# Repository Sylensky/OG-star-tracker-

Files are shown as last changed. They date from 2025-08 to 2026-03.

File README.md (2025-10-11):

# OG-star-tracker-

Is a fully 3d printed upgradable star tracker that you can make for 60$, I have been working on it for the past two years. It can handle
up to 300mm and 2.5kg. It's also upgradable which means that you can add a another axis which would allow you to use go-to.Don't hesitate to ask me. 
- [List of parts](https://docs.google.com/spreadsheets/d/1kcgIab0JqNLg5WMselIyCQLZJsu3P-vXLvSJgl1yHa8)
- [Assembly video](https://www.youtube.com/watch?v=97YKJrmOWHY)

## Table of Contents
- [Old v1 of the Project](v1/README.md)
- [Mechanics](mechanics/README.md)
- [Firmware](esp32_wireless_control/README.md)
- [Community Upgrades](community_upgrades/README.md)

The kit can be purchased for around 150$ on [ogstartech.com](https://www.ogstartech.com/start/). There is a [discord](https://discord.gg/dyFKm79gKJ) for those who are interested or would want to ask me a few questions. New STLs are
on [printables](https://www.printables.com/model/348574-og-star-tracker).

[DeepWiki](https://deepwiki.com/OG-star-tech/OG-star-tracker-/1-overview) Provides a very detailed documentation of the project.

## License

This work is licensed under a
[Creative Commons Attribution-NonCommercial-ShareAlike 4.0 International License](http://creativecommons.org/licenses/by-nc-sa/4.0/)



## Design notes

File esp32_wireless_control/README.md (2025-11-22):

# OG Star Tracker : Wireless Control Hardware (Rev 2.0)

This simple PCB and firmware intends to make it easier to control the OG Star Tracker. If you have any suggestions/ideas about new features or would like to contribute, post in the OG star tracker [discord server](https://discord.com/invite/dyFKm79gKJ) or message me (Discord: jahh#8924).
If you like this work, feel free to connect with me on [Github](https://github.com/jugal2001) or [Linkedin](https://www.linkedin.com/in/jugaljesing/).
### Features:
- Wirelessly Control the tracker from your phone/laptop by connecting to a webpage
- Supports AP (Access Point) and STA (Station) mode
 -- AP  : The ESP32 will create a wifi network which you can connect to
 -- STA : The ESP32 connects to an existing wifi network specified by you, Ex: phone hotspot. (Not fully tested)
- Integrated intervalometer which can control your camera shutter, no need to buy extra hardware. Exposures can be controlled via the webpage
  - Intervalometer Modes:
    - Long Exposure Still: Classic astro mode with tracking to get long exposures on the same target. Optional dithering.
    - Long Exposure Movie: Long exposures with tracking and dither plus at the end of a set of exposures the axis is rewound (a frame) and the next set started. This give the ability to create a movie          of the night sky moving over a terrestrial object when couple with a video making software.
    -  Day Time Lapse: Standard time lapse with exposure settings controlled by the camera.
    -  Day Time Lapse with Pan: Standard time lapse with exposure settings controlled by the camera plus a pan of X degrees in between every exposure.
- Presets : Up to 10 preset intervalometer settings can be saved for retrieval next session.
- USB port to power a Dew Heater
- Slewing supported at different speeds.

*If you would like to buy an assembled PCB, contact Ondra Gejdos in the discord server (Creator of the OGST). Alternatively, if you live in India contact me to buy the PCB.*

## Table of Contents
- [PCB](pcb/README.md)
- [Compiling](docs/compiling.md)
- [API](firmware/website/API.md)
- [Wifi Config](docs/wifi_config.md)
- [Star Catalogue](firmware/catalogues/README.md)
- [Coding Style](docs/coding-style.md)

## Building guide

One can get the full kit from the the official store at [ogstartech.com](https://ogstartech.com/start) or can build the tracker itself based on the instructions given at [printables](https://www.printables.com/model/348574-og-star-tracker)

## Firmware

The firmware for the PCB is provided in this repository and can be compiled and flashed with the given [instructions](docs/compiling.md).
To control the PCB the tracker will create its own wifi access point with the following default credentials:

```
ssid: OG Star Tracker
password: password123
```

After connection was successful the tracker to actually control it access the **tracker.local** in your browser. The ESP32 provides a webserver for convenient controlling.

If one would like to set it own wifi config, check [Wifi Config](docs/wifi_config.md).

## App

If the webserver is not enough there is a app available to improve the accessibility even further.
Check out https://github.com/OndraGejdos/OG-star-tracker-App for more details.

## Contributing

When contributing to the project please make sure to follow the [coding style](docs/coding-style.md) prior creating a pull request.
With this we can make sure to keep a clean and tidy codespace.

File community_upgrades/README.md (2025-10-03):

# Community Upgrades

You can upload your upgrades and modifications here.

Currently the following upgrades are available:

- [Power bank holder](./power_bank_holder/README.md) — Super simple power bank holder from #The1naruto
- [Surveyor tripod adapter](./surveyor_tripod_adapter/README.md) - Surveyor tripod adapter by #unfi_zero
- [Beefier gearbox multicolor](./beefier_gearbox_multicolor/README.md) - Beefier gearbox and multicolor support for certain elements by #Long
- [Illuminated Polarscope](./illuminated_polarscope/README.md) - Illuminated polarscope by #Long

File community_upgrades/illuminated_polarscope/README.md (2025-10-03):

## Illuminated Polarscope Mount

| Polarscope mount | Tracker mounted |
| --- | --- |
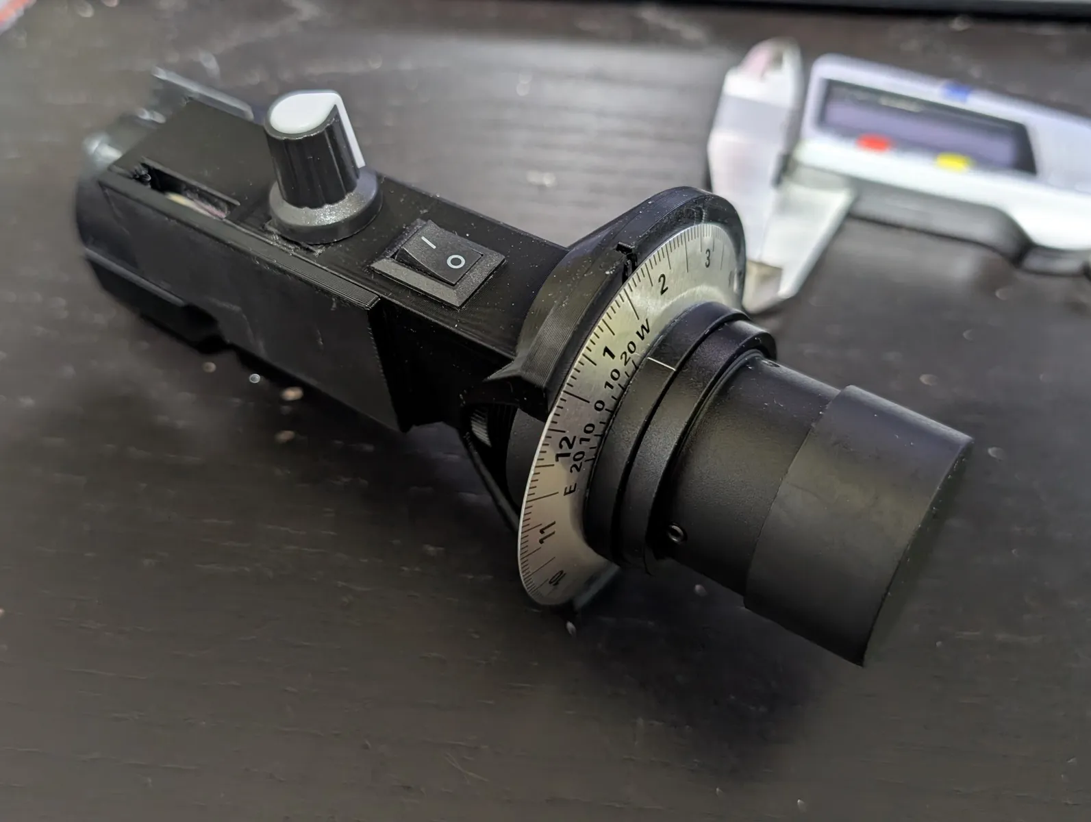
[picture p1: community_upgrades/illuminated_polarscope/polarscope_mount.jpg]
Polarscope mount
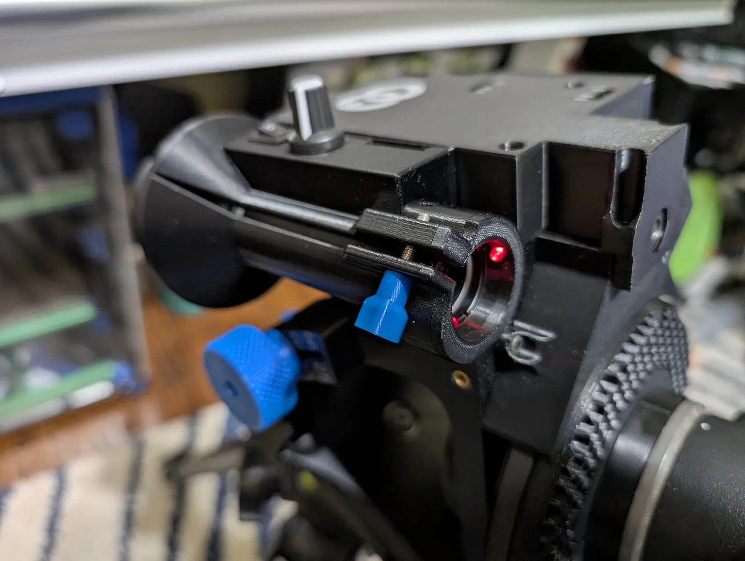
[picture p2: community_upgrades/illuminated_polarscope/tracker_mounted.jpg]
tracker mounted
|  |  |

### Intro:
This is a modified polar mount for the OG Star Tracker V2 that adds some LEDs.  Due to the small space constraints, it isn't the most straightforward build, but it does work pretty well once assembled.  

I used the switch and potentiometer I had on hand, which probably made it harder than just buying a potentiometer with a switch.  I will include the STEP file so it should be pretty easy to modify the electronics compartment to a a switched potentiometer if desired.

**IMPORTANT NOTE**:

This will only work with my single piece gearbox mod [here](../beefier_gearbox_multicolor/README.md) and the upcoming revision of the OG tracker, which will also combine the gearbox 1-2 pieces into a single piece.

### BOM:

- (1) - Polar Scope of this style https://www.amazon.com/dp/B0D2L11C4G 
- (2) - 3mm LEDs
- (2 ft) - >24 gauge wire. the thinner you have, the easier it will be.  I used 26g. 
    - the strands from an ethernet cable will probably work well
- (1 ft) - 20-22g wire.  
    - 20g will work if you have FEP or PTFE wire.
    - Can also use the thin gauge wire and just double/triple up the exposed wire ends.
    - This is used to make the contacts to the 2032 battery.
- (1) - 10 x 15mm mini rocker switch https://www.aliexpress.us/item/3256807801613950.html 
- (1) - WH148 5k ohm potentiometer https://www.aliexpress.us/item/2251832721838471.html 
    - Even lower than 5k is probably better, but all I see is 5k.
    - Any potentiometer that attaches with a nut will probably work as long as it is smaller than the WH148, which is actually kind of big.
- (1) - 2032 battery (3v)
- (1) - 4.2mm brass heatset (from Star Tracker BOM)
- Superglue

Printables link: https://www.printables.com/model/1293141-og-star-tracker-v2-illuminated-polar-scope-mount

The printables link also contains the detailed guide.

Credits go to #Long from discord

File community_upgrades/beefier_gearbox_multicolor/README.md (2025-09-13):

## Surveyor Tripod Adapter

| Front | STL |
| --- | --- |
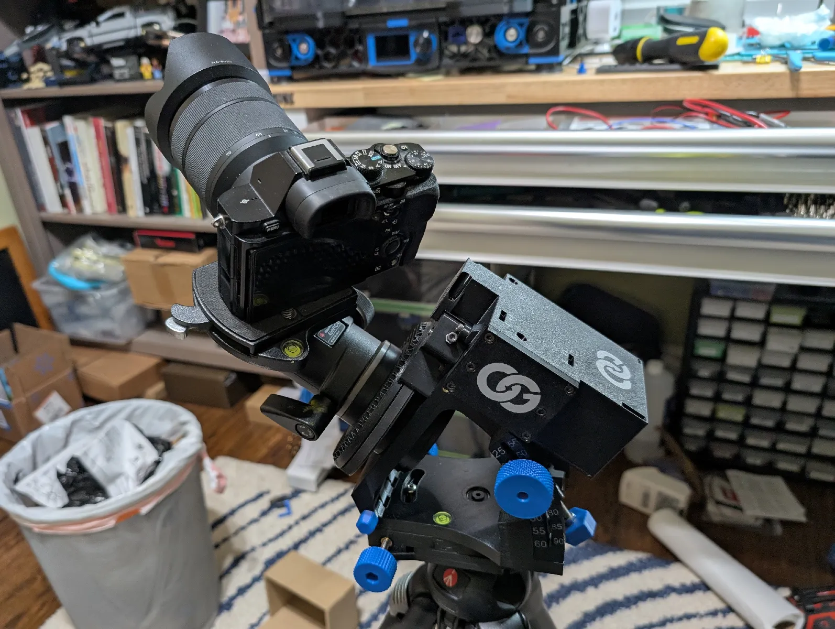
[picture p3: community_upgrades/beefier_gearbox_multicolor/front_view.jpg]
Front view
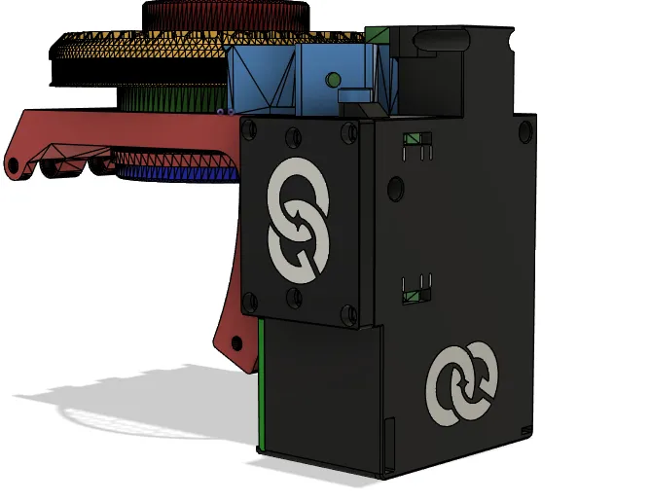
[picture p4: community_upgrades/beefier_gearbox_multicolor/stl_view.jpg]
stl view
|  |  |

### Intro:
These are a few mods to the excellent design of the OG Star Tracker V2.  After building it initially, I wanted to make a few changes to the gearbox to make it a little beefier and make a few small aesthetic changes.  

### Changes impacting strength
- Combines gearbox part 1 and part 2 into one piece for a cleaner look and improved rigidity.
- Thickens the back face of the combined part 1 and 2 for extra rigidity.
- Adds additional bracing to the 625 bearing mount that the tightener pulls against.
- Thickens the mount for the NEMA 17 stepper.  
- Adds additional mounting point for the belt cover to keep it from lifting when pushing against the 400mm belt.

### Other Changes
- The files are now multi-material files with separate bodies for colors so you no longer have to do multi-material painting. 
- Added the logo to the [doors]
- added optional idler carriers
- added camera holder that uses a 3/8"-16 x ½" bolt versus the ¼"-20 x ½"

### Downsides
It is a little more tricky to assemble because access to a couple the bolts is slightly worse.  However, I think it is worth it.

All files are within the **stls** folder. Update will likely land first on the printables page.

Printables link: https://www.printables.com/model/1262022-og-star-tracker-v2-mods-single-piecebeefier-gearbo

Credits go to #Long from discord

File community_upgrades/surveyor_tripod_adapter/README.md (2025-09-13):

## Surveyor Tripod Adapter

| Top | Side |
| --- | --- |
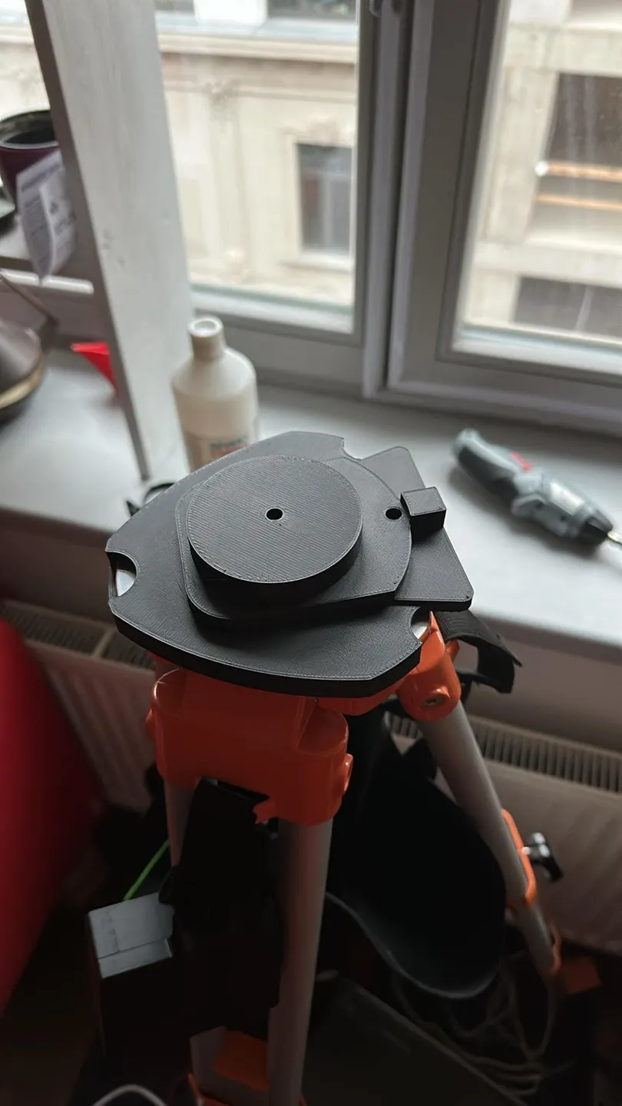
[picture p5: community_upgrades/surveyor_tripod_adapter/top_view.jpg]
Top view
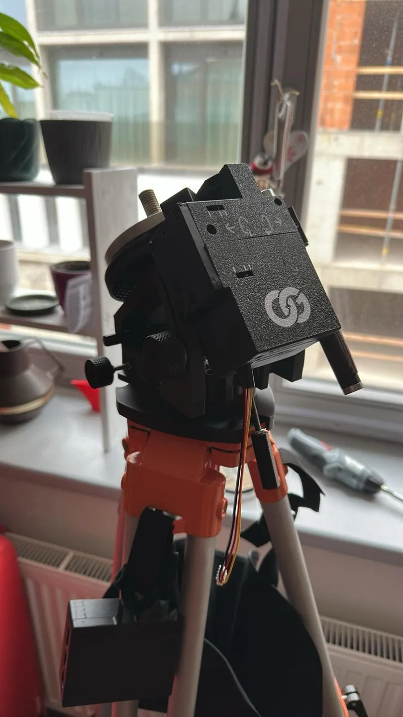
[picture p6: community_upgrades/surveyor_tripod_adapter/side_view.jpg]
Side view
|  |  |

Surveyor tripod adapter so that the OG Star Tracker V2 will not move on the tripod.

perfect fit for https://geo-fennel.de/produkte/stative-und-nivellierlatten/alustative/fs-20

You can test your fit by printing the “size-test.stl” first.

Printables link: https://www.printables.com/model/1151274-og-star-tracker-v2-surveyor-tripod-adapter

Credits go to #unfi_zero from discord

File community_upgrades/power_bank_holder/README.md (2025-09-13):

## Super simple power bank holder

| Front | Back |
| --- | --- |
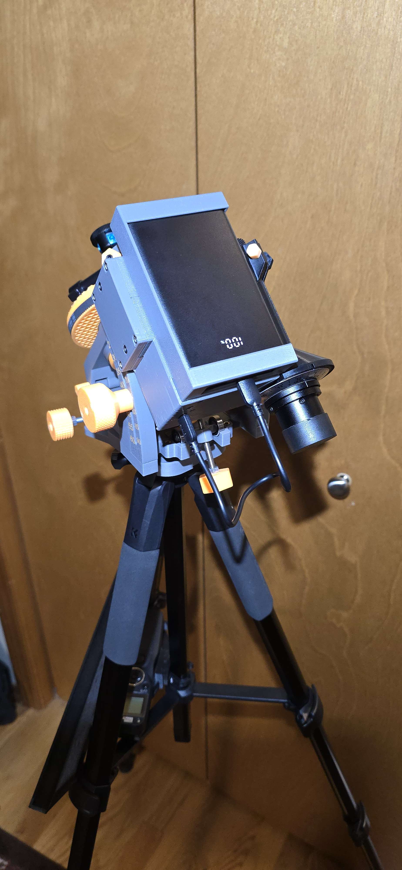
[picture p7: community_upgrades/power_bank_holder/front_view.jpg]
Front view
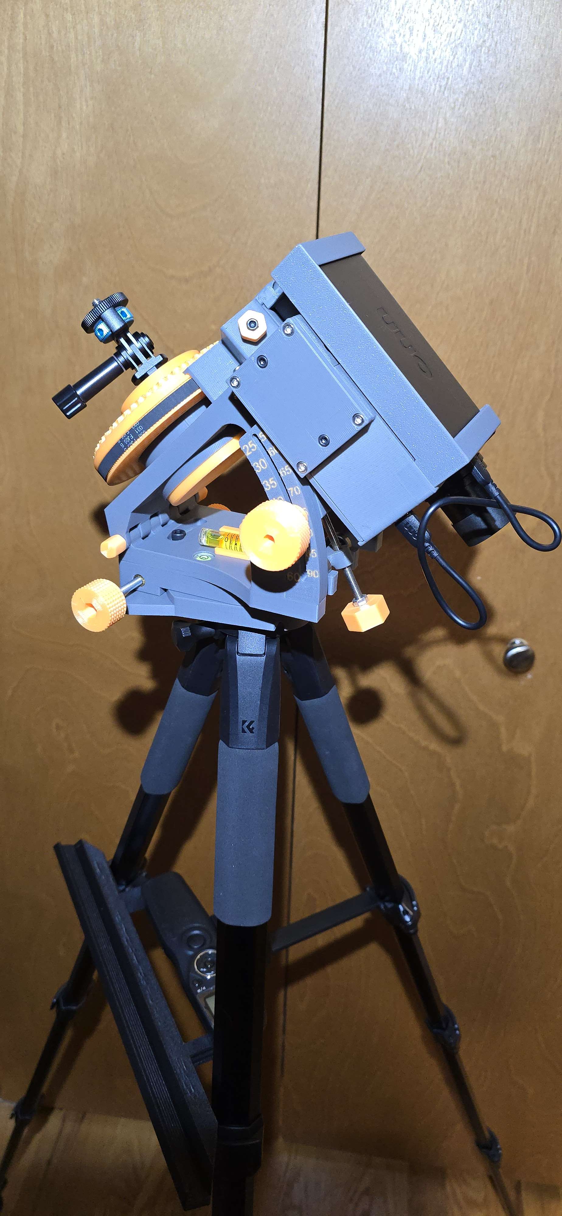
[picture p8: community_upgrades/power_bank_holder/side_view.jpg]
Side view
|  |  |

Super simple design for using the phone mount spot for an ONN 5800mAh power bank to power the tracker

Credits go to #The1naruto from discord

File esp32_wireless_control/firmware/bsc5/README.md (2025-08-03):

# BSC5 Data and Conversion

## Source
- The Yale Bright Star Catalog (BSC5) is available at following link:
  - http://tdc-www.harvard.edu/catalogs/bsc5.html
- Download the main data file (e.g., `bsc5.dat`) from the FTP archive.

## JSON Format Support
The BSC5 class now supports JSON format data for easier integration with modern applications:

### Conversion Scripts
- Python scripts are provided in this folder to convert the BSC5 data to JSON:
  ```sh
  python bsc5_to_json.py
  python bsc5ra_to_json.py
  ```

### Using JSON Data
1. Add the JSON file to your PlatformIO configuration:
   ```ini
   [env:esp32]
   board_build.embed_txtfiles = bsc5/bsc5ra_stars_with_notes.json
   ```

2. Initialize the BSC5 class with JSON data:
   ```cpp
   #include "bsc5ra.h"
   
   // Load JSON data
   bsc5.loadFromJson(bsc5ra_stars_with_notes_json_start);
   
   // Find star by catalog number
   StarEntry star;
   if (bsc5.findStarByXno(15, star)) {
       star.print();
   }
   
   // Find star by name (partial, case-insensitive)
   if (bsc5.findStarByName("deneb", star)) {
       star.print();
   }
   ```

### Available Methods
- `findStarByXno(float xno, StarEntry& result)` - Find star by catalog number
- `findStarByName(const String& name_fragment, StarEntry& result)` - Find star by name (supports partial matching)
- `printStar(const StarEntry& star)` - Print star information
- `getStarCount()` - Get total number of stars loaded

## Notes
- The JSON format includes star names, notes, and proper motion data
- Name search is case-insensitive and supports partial matching (e.g., "deneb" will find "DENEB")
- Original binary format is still supported for backward compatibility

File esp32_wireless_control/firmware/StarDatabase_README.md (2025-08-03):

# StarDatabase - Unified Catalog System

The StarDatabase system provides a unified interface for accessing both stellar and deep-sky object catalogs in the ESP32 star tracker firmware.

## Overview

The StarDatabase acts as a parent class that manages multiple astronomical catalogs:
- **BSC5 (Yale Bright Star Catalog)**: Contains ~9,000 bright stars with proper names
- **NGC 2000.0**: Contains nebulae, galaxies, star clusters, and other deep-sky objects

## Architecture

```
StarDatabase (Parent Class)
├── BSC5 Integration (Stars)
│   ├── Star search by name/fragment
│   ├── Stellar coordinates and magnitudes
│   └── Spectral types and proper motion
└── NGC2000 Integration (Deep-Sky Objects)
    ├── Object search by name/type/constellation
    ├── Deep-sky coordinates and magnitudes
    └── Object sizes and descriptions
```

## Key Features

### 1. Unified Search Interface
```cpp
UnifiedEntry obj;

// Search across all loaded databases
starDB.findByName("Sirius", obj);
starDB.findByNameFragment("NGC", obj);
starDB.findBrighterThan(3.0, obj);
```

### 2. Database Switching
```cpp
// Use only stars
starDB.setActiveDatabase(DB_BSC5);

// Use only deep-sky objects  
starDB.setActiveDatabase(DB_NGC2000);

// Search both databases
starDB.setActiveDatabase(DB_BOTH);
```

### 3. Type-Specific Searches
```cpp
// Find stellar objects only
starDB.findStar("Deneb", obj);

// Find deep-sky objects only
starDB.findDeepSkyObject("NGC1234", obj);
```

### 4. Coordinate Utilities
```cpp
// Format coordinates for display
String coords = starDB.formatCoordinates(ra_deg, dec_deg);

// Calculate angular separation
double separation = starDB.angularSeparation(ra1, dec1, ra2, dec2);
```

## Data Structures

### UnifiedEntry
Common structure for all astronomical objects:
```cpp
struct UnifiedEntry {
    String name;           // Object name
    String type_str;       // Object type
    double ra_deg;         // Right Ascension (degrees)
    double dec_deg;        // Declination (degrees)
    float magnitude;       // Visual magnitude
    String constellation;  // Constellation (if available)
    DatabaseType source_db; // Source database
    bool is_star;          // Stellar object flag
    bool is_deep_sky;      // Deep-sky object flag
    
    // Extended data
    String spectral_type;  // For stars (BSC5)
    float size_arcmin;     // For deep-sky objects (NGC)
    String notes;          // Additional information
};
```

## Usage Examples

### Basic Setup
```cpp
#include "star_database.h"

void setup() {
    // Load catalogs
    starDB.loadBSC5(bsc5_json_data);
    starDB.loadNGC2000(ngc_json_data);
    
    // Set active database
    starDB.setActiveDatabase(DB_BOTH);
    
    // Print database info
    starDB.printDatabaseInfo();
}
```

### Object Search
```cpp
UnifiedEntry obj;

// Find by exact name
if (starDB.findByName("Vega", obj)) {
    starDB.printObject(obj);
}

// Find by name fragment
if (starDB.findByNameFragment("Alpha", obj)) {
    print_out("Found: %s", obj.name.c_str());
}

// Find bright objects
if (starDB.findBrighterThan(2.0, obj)) {
    print_out("Bright object: %s (mag %.2f)", 
              obj.name.c_str(), obj.magnitude);
}
```

### Telescope Integration
```cpp
// Goto command example
UnifiedEntry target;
if (starDB.findByName("M42", target)) {
    telescope.slewTo(target.ra_deg, target.dec_deg);
    print_out("Slewing to %s at %s", 
              target.name.c_str(),
              target.getCoordinateString().c_str());
}
```

## Database Backends

### BSC5 Integration
- **Data Source**: Yale Bright Star Catalog (5th Edition)
- **Object Count**: ~9,000 stars
- **Coordinate System**: J2000
- **Key Fields**: Name, spectral type, magnitude, proper motion
- **Search Methods**: By name fragment, stellar ID

### NGC2000 Integration  
- **Data Source**: New General Catalogue and Index Catalogue
- **Object Count**: Variable (filtered by magnitude/type)
- **Coordinate System**: J2000
- **Key Fields**: Name, object type, size, constellation
- **Search Methods**: By name, type, constellation, magnitude

## Performance Considerations

### Memory Usage
- Uses ArduinoJson for efficient JSON parsing
- Unified data structures minimize memory overhead
- Lazy loading of catalog data

### Search Performance
- Direct JSON traversal for name-based searches
- Type-specific searches route to appropriate backend
- Caching of frequently accessed objects (future enhancement)

## File Structure

```
firmware/
├── star_database.h              # Main header
├── star_database.cpp            # Implementation
├── star_database_example.cpp    # Usage examples
├── bsc5/
│   ├── bsc5ra.h                # BSC5 star catalog
│   ├── bsc5ra.cpp              # BSC5 implementation
│   └── bsc5ra_stars_with_notes.json
└── ngc/
    ├── ngc2000.h               # NGC catalog
    ├── ngc2000.cpp             # NGC implementation
    └── ngc2000.json
```

## Integration with Existing Code

### UART Output
All output uses the project's `print_out()` function from `uart.h`:
```cpp
print_out("Found object: %s", obj.name.c_str());
```

### JSON Data Loading
Compatible with PlatformIO embedded file system:
```cpp
extern const char bsc5_json_data[];
extern const char ngc_json_data[];
```

### Arduino Framework
Full compatibility with ESP32 Arduino framework and existing project structure.

## Future Enhancements

### Planned Features
1. **Proximity Search**: Find objects near telescope position
2. **Visibility Calculations**: Filter by altitude/azimuth
3. **Observing Lists**: Create custom target lists
4. **Messier Integration**: Cross-reference NGC objects with Messier numbers
5. **Search Caching**: Improve performance for repeated searches

### API Extensions
1. **Multiple Result Search**: Return arrays of matching objects
2. **Advanced Filtering**: By magnitude range, object size, etc.
3. **Coordinate Transformations**: Alt/Az calculations
4. **Time-based Visibility**: Rise/set times and optimal viewing

## Error Handling

The system includes comprehensive error handling:
- JSON parsing validation
- Database loading verification
- Search result validation
- Memory management for large catalogs

## Debugging

Enable detailed output for troubleshooting:
```cpp
starDB.printDatabaseInfo();  // Database status
obj.print();                 // Object details
```

Use the project's existing UART debugging system for consistent logging across all modules.

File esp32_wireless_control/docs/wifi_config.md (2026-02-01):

# Wifi Config

## `platformio.ini` changes

The `platformio.ini` file *must* define a macro `HAVE_WIFI_CONFIG` in order to config to detect wifi configuration:

Example:
```yaml
build_flags =
    -D HAVE_WIFI_CONFIG=1
    -D AP_MODE=1
    -D BINARY_NAME=${ogstartracker.custom_binary_name}
    -D VERSION=${ogstartracker.custom_version}
    -D DEBUG=0
    -D MDNS_NAME='"tracker"'
    -D BUILD_VERSION=\"${ogstartracker.custom_version}\"
    -D INTERNAL_VERSION=7
    -D WIFI_SSID='"OG Star Tracker"'
    -D WIFI_PASSWORD='"password123"'
    -D STEPPER_TYPE=STEPPER_0_9
    -D WEBSERVER_PORT=80
    -D AP_MODE=1
    -D TRACKING_RATE=TRACKING_SIDEREAL
    -Wall -Wextra -Os
```

## `wifi_config.h` file

One must a file called `wifi_config.h` with his/hers own wifi network credentials:

```c
#ifndef _WIFI_CONFIG_H_
#define _WIFI_CONFIG_H_

#define WIFI_SSID "your ssid here"
#define WIFI_PASSWORD "your wifi password"

#endif /* _WIFI_CONFIG_H_ */

```

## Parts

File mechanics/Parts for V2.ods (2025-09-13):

parts | quantity | remarks
M3x40 socket bolt | 4
M3x6 socket bolt | 2
M3x20 socket bolt | 8
M5x25 socket bolt | 1
M5x50 Hex head | 2
M5 ptfe washer | 1
M3x8 socket bolt | 40
M3x16 socket bolt | 4
M5x20 Low profile socket bolt | 1
¼-20x1/2” UNC Hex head | 2
m3 threaded insert | 60
m5 threaded insert | 5
- | 1
M3 nut | 3
M5 nut | 3
M5 self-tightening nuts | 2
¼-20 UNC to 3/8-20 UNC adapter | 2
AXK 5070 needle bearing | 2
AS 5070 Axial bearing washer | 4
KU 5025 plain bearing | 1 | It’s a ptfe lined plain bearing with dimensions of : Inner diameter : 50mm Outer diameter 55mm, Witdth : 25mm
GT2 16 teeth pulley | 3
GT2 48 teeth pulley | 2
GT2 20 teeth idler | 1
GT2 120mm belt | 2
GT2 400mm belt | 1
5x50mm shaft | 2
M5x95mm rod | 1
M5x135mm rod | 1
625 bearing | 10
Round bubble level 12x7mm | 1
Laser or polar scope | 1
4mm hex key | 1
2.5mm hex key | 1
grease, ptfe based | 1
glue | 1
2mm hex key | 1
Round magnet 10x3mm | 4
Round magnet 5x5mm | 2
PCB ( buy at ogstartech.com) | 1 | https://ogstartech.com/product/og-star-tracker-pcb-board/
Stepper motor | 1
cable for stepper motor | 1

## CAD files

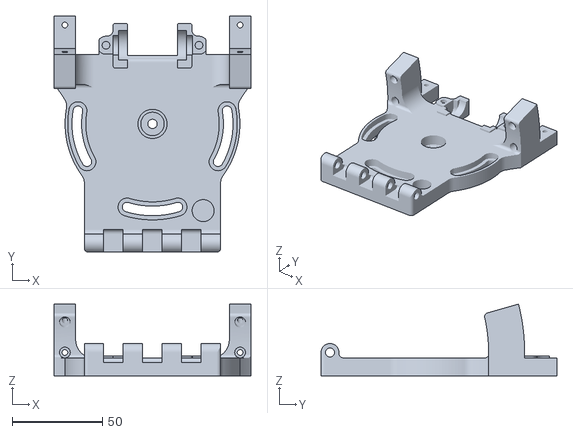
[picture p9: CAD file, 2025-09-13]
mechanics/Heavy duty/main-bottom-part-hd.stl
109.2 x 130.9 x 39.9

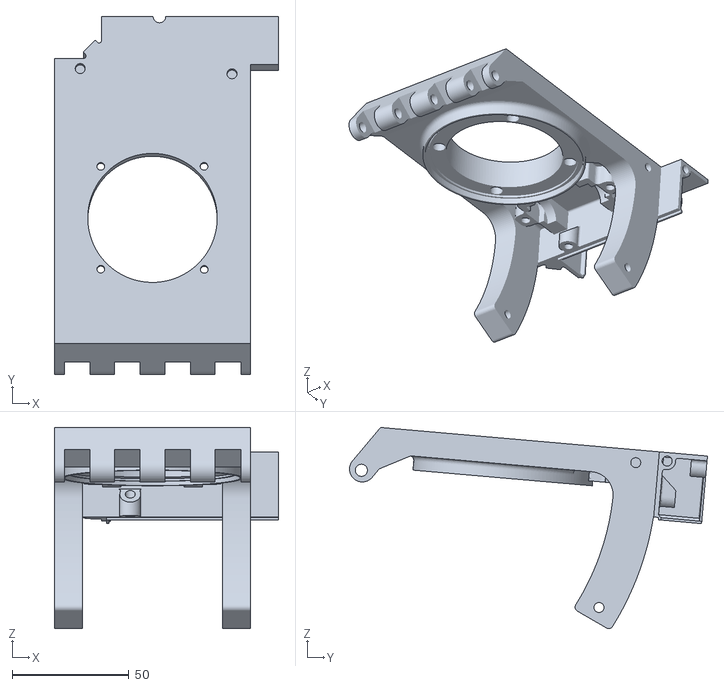
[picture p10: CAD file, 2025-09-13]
mechanics/Heavy duty/main-top-part-hd.stl
96.2 x 153.4 x 86.2

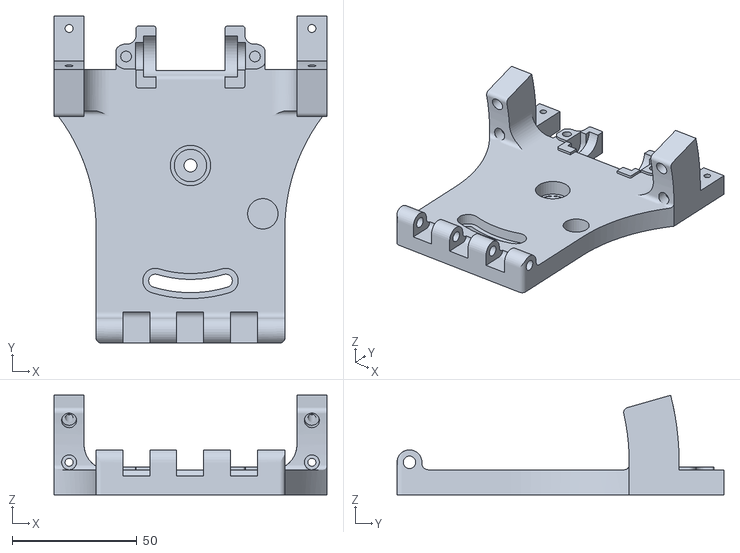
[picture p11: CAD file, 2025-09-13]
mechanics/V2 files/main-bottom-part.stl
109.2 x 130.9 x 39.9

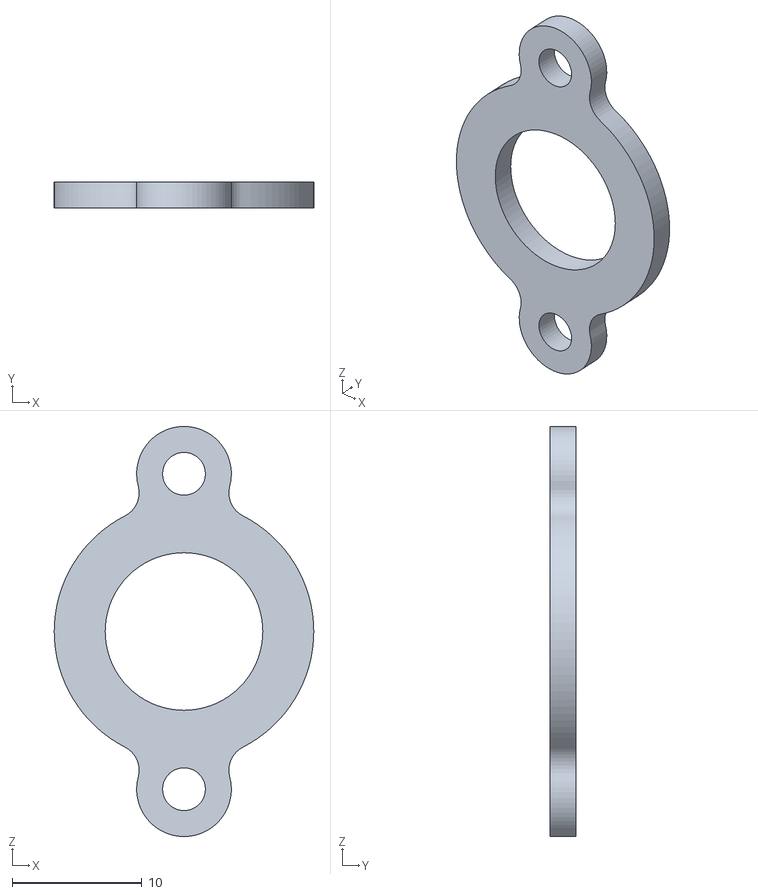
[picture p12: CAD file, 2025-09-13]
mechanics/V2 files/main-gearbox-bearing-holderstl.stl
20.0 x 2.00 x 31.6

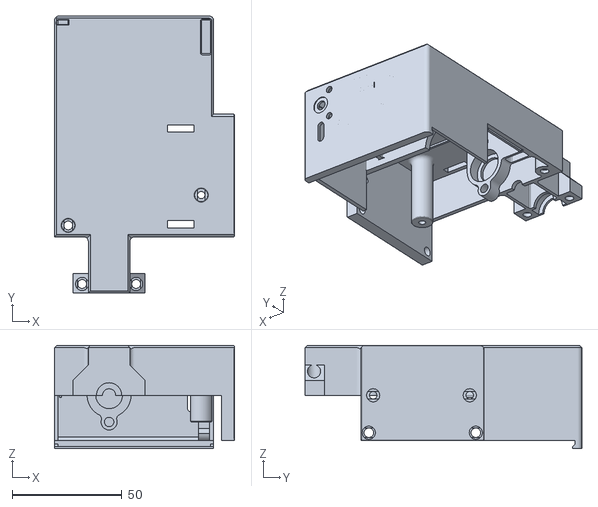
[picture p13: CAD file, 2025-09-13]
mechanics/V2 files/main-gearbox.stl
82.0 x 126.2 x 47.0

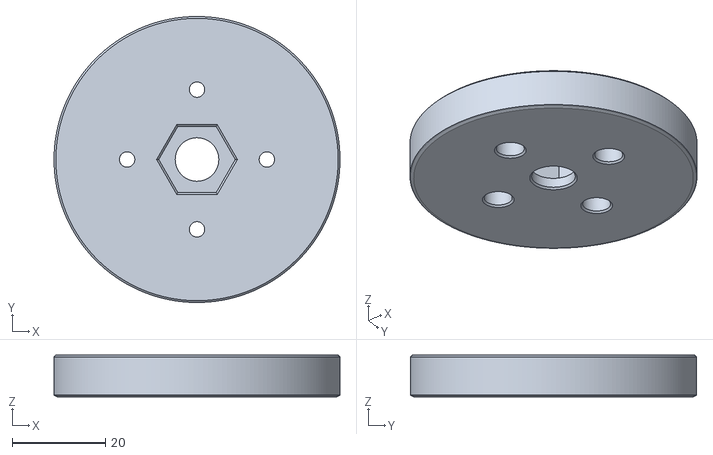
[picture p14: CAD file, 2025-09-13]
community_upgrades/beefier_gearbox_multicolor/stls/camera-holder-3-8-16-x-1-2.stl
61.4 x 61.4 x 9.00

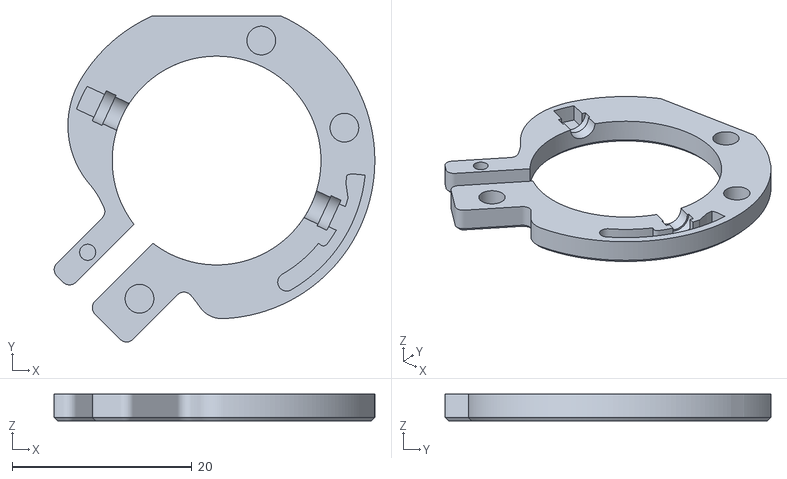
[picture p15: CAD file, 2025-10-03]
community_upgrades/illuminated_polarscope/stls/led-top-cap.stl
35.7 x 36.3 x 3.00

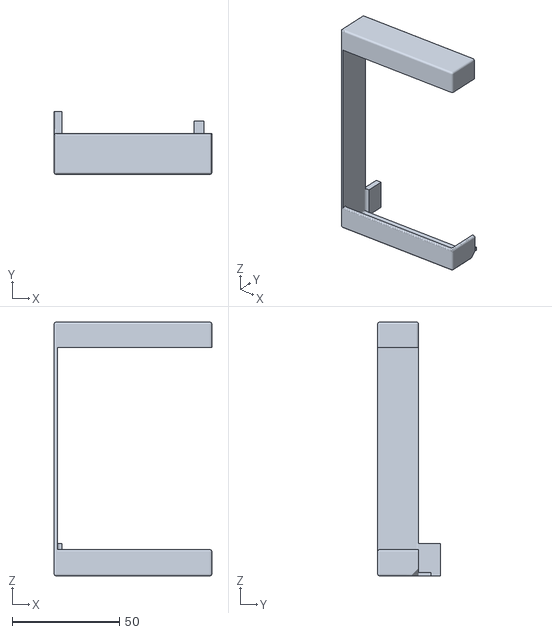
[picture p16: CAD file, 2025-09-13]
community_upgrades/power_bank_holder/OGstartracker ONN battery mount.stl
73.4 x 29.2 x 118.2

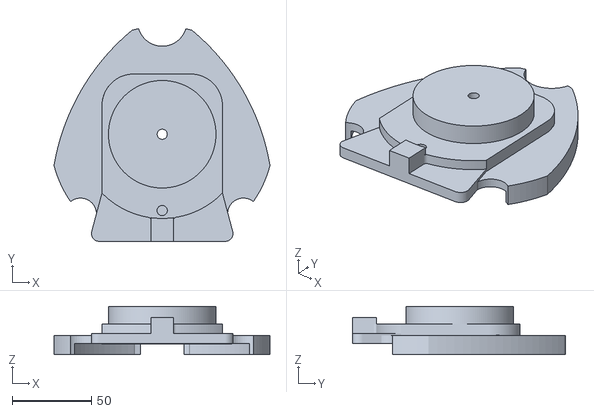
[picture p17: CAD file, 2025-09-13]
community_upgrades/surveyor_tripod_adapter/stationary_part_with_surveyor_adapter2.stl
136.6 x 134.6 x 30.6

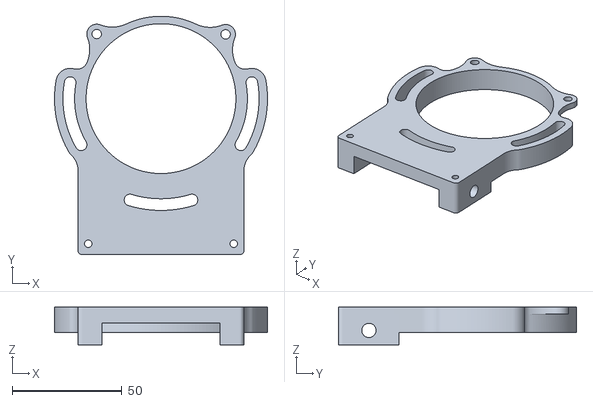
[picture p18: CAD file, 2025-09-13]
mechanics/Heavy duty/middle-part-hd.stl
97.0 x 108.6 x 17.1

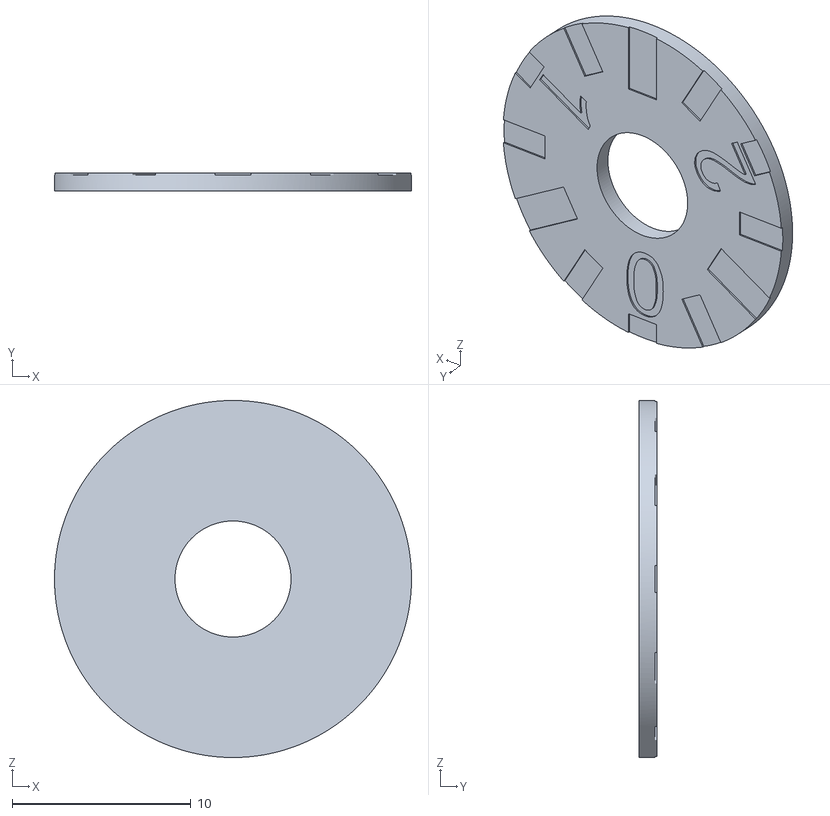
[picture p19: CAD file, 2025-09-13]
mechanics/Manual go-to beta testing/small-scale-2.stl
20.0 x 1.00 x 20.0

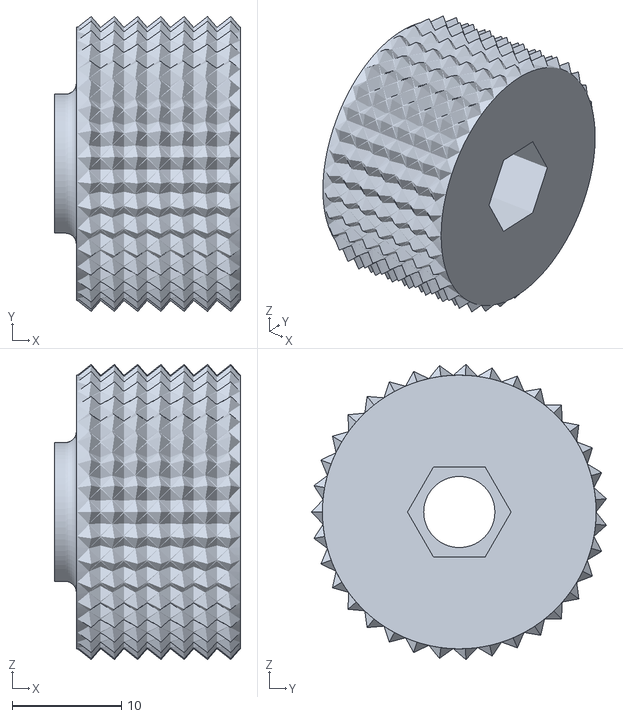
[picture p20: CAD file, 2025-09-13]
mechanics/V2 files/m5-knob.stl
17.0 x 26.9 x 27.0

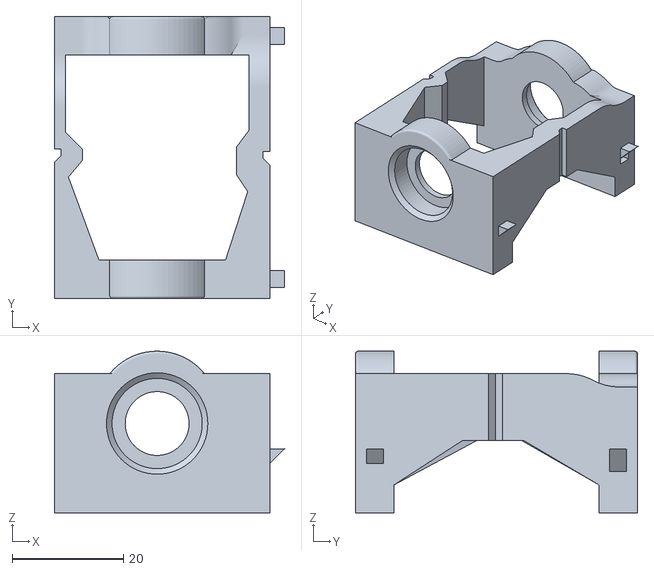
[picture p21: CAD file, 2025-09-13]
community_upgrades/beefier_gearbox_multicolor/stls/tightener-modded-needs_supports.stl
41.3 x 50.7 x 29.1

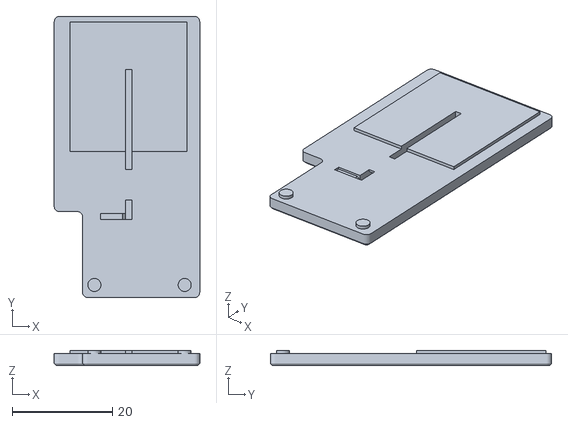
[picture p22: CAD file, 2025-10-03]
community_upgrades/illuminated_polarscope/stls/side-cap.stl
29.0 x 56.0 x 3.00

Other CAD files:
mechanics/V2 files/main-top-part.stl
community_upgrades/surveyor_tripod_adapter/size-test.stl
mechanics/Heavy duty/arcs-for-hd.stl
mechanics/Manual go-to beta testing/vixen-knob.stl
community_upgrades/beefier_gearbox_multicolor/stls/belt-cover-modded-needs_supports.stl
community_upgrades/beefier_gearbox_multicolor/stls/belt-tightener-625-bearing-m5x16mm.stl
community_upgrades/beefier_gearbox_multicolor/stls/belt-tightener-f695-bearing-m5x16mm.stl
community_upgrades/beefier_gearbox_multicolor/stls/doors-modded-with-logo.stl
community_upgrades/beefier_gearbox_multicolor/stls/gearbox-part-1-2-combined-embossed_letters-v11.stl
community_upgrades/beefier_gearbox_multicolor/stls/gearbox-part-1-2-combined-with-multicolor-letters-v11.stl
community_upgrades/beefier_gearbox_multicolor/stls/gearbox-part-3-modded.stl
community_upgrades/illuminated_polarscope/stls/knob.stl
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

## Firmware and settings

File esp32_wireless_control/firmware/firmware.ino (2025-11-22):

#include <ArduinoJson.h>
#include <ESPmDNS.h>
#include <ErriezSerialTerminal.h>
#include <WebServer.h>
#include <WiFi.h>
#include <esp_wifi.h>
#include <freertos/FreeRTOS.h>
#include <string.h>

#include "axis.h"
#include "catalogues/star_database.h"
#include "commands.h"
#include "common_strings.h"
#include "configs/config.h"
#include "eeprom_manager.h"
#include "functions/intervalometer/intervalometer.h"
#include "functions/ota/ota_handler.h"
#include "hardwaretimer.h"
#include "tracking_rates.h"
#include "uart.h"
#include "website/api_handler.h"
#include "website/web_languages.h"
#include "website/website_strings.h"

SerialTerminal term(CLI_NEWLINE_CHAR, CLI_DELIMITER_CHAR);
WebServer server(WEBSERVER_PORT);
Languages language = EN;
StarDatabase* starDatabase = nullptr;
Intervalometer* intervalometer = nullptr;

void uartTask(void* pvParameters);
void consoleTask(void* pvParameters);
void webserverTask(void* pvParameters);
void intervalometerTask(void* pvParameters);
void systemShutdown();

extern const uint8_t _interface_index_html_start[] asm("_binary_interface_index_html_start");
extern const uint8_t _interface_index_html_end[] asm("_binary_interface_index_html_end");

extern const uint8_t _catalogues_ngc_converted_ngc2000_bin_start[] asm(
    "_binary_catalogues_ngc_converted_ngc2000_bin_start");
extern const uint8_t _catalogues_ngc_converted_ngc2000_bin_end[] asm(
    "_binary_catalogues_ngc_converted_ngc2000_bin_end");

extern const uint8_t _catalogues_ngc_converted_ngc2000_compact_bin_start[] asm(
    "_binary_catalogues_ngc_converted_ngc2000_compact_bin_start");
extern const uint8_t _catalogues_ngc_converted_ngc2000_compact_bin_end[] asm(
    "_binary_catalogues_ngc_converted_ngc2000_compact_bin_end");

extern const uint8_t _catalogues_bsc5_converted_bsc5ra_bin_start[] asm(
    "_binary_catalogues_bsc5_converted_bsc5ra_bin_start");
extern const uint8_t _catalogues_bsc5_converted_bsc5ra_bin_end[] asm(
    "_binary_catalogues_bsc5_converted_bsc5ra_bin_end");

extern const uint8_t _catalogues_bsc5_converted_bsc5ra_compact_bin_start[] asm(
    "_binary_catalogues_bsc5_converted_bsc5ra_compact_bin_start");
extern const uint8_t _catalogues_bsc5_converted_bsc5ra_compact_bin_end[] asm(
    "_binary_catalogues_bsc5_converted_bsc5ra_compact_bin_end");

StarDatabase* handleStarDatabase(StarDatabaseType type)
{
    StarDatabase* db = nullptr;
    const uint8_t* bin_start = nullptr;
    const uint8_t* bin_end = nullptr;
    size_t len = 0;

    if (starDatabase != nullptr && starDatabase->getDatabaseType() == type)
        return starDatabase; // Return existing instance if already loaded

    if (starDatabase != nullptr)
    {
        starDatabase->unloadDatabase();
        delete starDatabase;
        starDatabase = nullptr;
    }

    switch (type)
    {
        case DB_NGC2000:
            bin_start = _catalogues_ngc_converted_ngc2000_bin_start;
            bin_end = _catalogues_ngc_converted_ngc2000_bin_end;
            len = bin_end - bin_start;
            break;
        case DB_NGC2000_COMPACT:
            bin_start = _catalogues_ngc_converted_ngc2000_compact_bin_start;
            bin_end = _catalogues_ngc_converted_ngc2000_compact_bin_end;
            len = bin_end - bin_start;
            break;
        case DB_BSC5:
            bin_start = _catalogues_bsc5_converted_bsc5ra_bin_start;
            bin_end = _catalogues_bsc5_converted_bsc5ra_bin_end;
            len = bin_end - bin_start;
            break;
        case DB_BSC5_COMPACT:
            bin_start = _catalogues_bsc5_converted_bsc5ra_compact_bin_start;
            bin_end = _catalogues_bsc5_converted_bsc5ra_compact_bin_end;
            len = bin_end - bin_start;
            break;
        default:
            print_out("Error: Unsupported database type %d", type);
            return nullptr;
    }

    db = new StarDatabase(type, bin_start, bin_end);
    if (!db->loadDatabase((const char*) bin_start, len))
    {
        delete db;
        return nullptr;
    }

    return db;
}

String getChipID()
{
    uint64_t chipid = ESP.getEfuseMac();
    uint8_t baseMac[6];

    // Extract each byte of the MAC address from the chipid
    baseMac[0] = (chipid >> 40) & 0xFF;
    baseMac[1] = (chipid >> 32) & 0xFF;
    baseMac[2] = (chipid >> 24) & 0xFF;
    baseMac[3] = (chipid >> 16) & 0xFF;
    baseMac[4] = (chipid >> 8) & 0xFF;
    baseMac[5] = chipid & 0xFF;

    // Create a String object to hold the formatted ID
    String id = String(baseMac[4], HEX) + String(baseMac[5], HEX);
    return id;
}

#if DEBUG == 1
void handleNotFound()
{
    print_out("HTTP 404: %s %s", server.method() == HTTP_GET ? "GET" : "POST",
              server.uri().c_str());
    print_out("  Client: %s", server.client().remoteIP().toString().c_str());
    print_out("  User-Agent: %s", server.header("User-Agent").c_str());
    server.send(404, MIME_TYPE_TEXT, "Not Found");
}
#endif

void setupWireless()
{
#if AP_MODE == 1
    // Create unique SSID for each device
    String chipID = getChipID();
    char ssid[32];
    sprintf(ssid, "%s#%s", WIFI_SSID, chipID.c_str());

    WiFi.mode(WIFI_MODE_AP);
    print_out("Creating Wifi Network: %s", ssid);

    // Configure AP with specific IP settings
    IPAddress local_IP(192, 168, 4, 1);
    IPAddress gateway(192, 168, 4, 1);
    IPAddress subnet(255, 255, 255, 0);

    if (!WiFi.softAPConfig(local_IP, gateway, subnet))
    {
        print_out("Failed to configure AP IP settings");
    }

    if (!WiFi.softAP(ssid, WIFI_PASSWORD))
    {
        print_out("Failed to start AP");
    }

    vTaskDelay(1000); // Give more time for AP to initialize

    // ANDROID 10 WORKAROUND==================================================
    // set new WiFi configurations
    print_out("Applying Android 10 compatibility workaround...");
    WiFi.disconnect();
    /*Stop wifi to change config parameters*/
    esp_wifi_stop();
    esp_wifi_deinit();
    /*Disabling AMPDU RX is necessary for Android 10 support*/
    wifi_init_config_t my_config = WIFI_INIT_CONFIG_DEFAULT(); // We use the default config ...
    my_config.ampdu_rx_enable = 0;                             //... and modify only what we want.
    print_out("WiFi: Disabled AMPDU...");
    esp_wifi_init(&my_config); // set the new config = "Disable AMPDU"
    esp_wifi_start();          // Restart WiFi

    // Restart AP after workaround
    WiFi.mode(WIFI_MODE_AP);
    if (!WiFi.softAPConfig(local_IP, gateway, subnet))
    {
        print_out("Failed to reconfigure AP IP settings after workaround");
    }
    if (!WiFi.softAP(ssid, WIFI_PASSWORD))
    {
        print_out("Failed to restart AP after workaround");
    }

    vTaskDelay(1000);
    // ANDROID 10 WORKAROUND==================================================

    print_out("AP setup complete. Checking status...");
    print_out("AP Status: %s", WiFi.softAPgetStationNum() >= 0 ? "Active" : "Inactive");
    print_out("WiFi Mode: %d", WiFi.getMode());
#else
    WiFi.mode(WIFI_MODE_STA); // Set ESP32 in station mode
    WiFi.begin(WIFI_SSID, WIFI_PASSWORD);
    print_out("Connecting to SSID: %s with password: %s", WIFI_SSID, WIFI_PASSWORD);
    print_out("Connecting to Network in STA mode");
    while (WiFi.status() != WL_CONNECTED)
    {
        vTaskDelay(1000);
        print_out(".");
    }
#endif

    // Initialize OTA Handler (singleton)
    OTAHandler::getInstance().init(&server);

    // Register all REST API endpoints using ApiHandler
    ApiHandler::getInstance().init(&server);
    ApiHandler::getInstance().registerEndpoints();

#if DEBUG == 1
    server.onNotFound(handleNotFound);
    print_out("Web server debug logging enabled");
#endif

    // Start the server
    server.begin();

#if AP_MODE == 1
    IPAddress apIP = WiFi.softAPIP();
    print_out("AP IP address: %s", apIP.toString().c_str());
    if (apIP == IPAddress(0, 0, 0, 0))
    {
        print_out("ERROR: AP IP is 0.0.0.0 - AP may not be configured correctly");
        print_out("WiFi Mode: %d", WiFi.getMode());
        print_out("AP Status: %d", WiFi.status());
    }
#else
    print_out("STA IP address: %s", WiFi.localIP().toString().c_str());
#endif

    print_out("Starting mDNS responder");
    if (!MDNS.begin(MDNS_NAME))
    {
        print_out("Error starting mDNS responder");
        return;
    }
    print_out("mDNS responder started");

    MDNS.addService("http", "tcp", WEBSERVER_PORT);
    MDNS.addServiceTxt("http", "tcp", "ogtracker", "1");
    MDNS.addServiceTxt("http", "tcp", "version", BUILD_VERSION);

    MDNS.addService("ogtracker", "tcp", WEBSERVER_PORT);
    MDNS.addServiceTxt("ogtracker", "tcp", "version", BUILD_VERSION);
}

void setup()
{
    // Start the debug serial connection
    setup_uart(&Serial, 115200);

    // start UART task before any usage of print_out
    if (xTaskCreatePinnedToCore(uartTask, "uart", 4096, NULL, 1, NULL, 1))
    {
        print_out_tbl(TSK_CLEAR_SCREEN);
        print_out_tbl(TSK_START_UART);
    }

    print_out_tbl(HEAD_LINE);
    print_out_tbl(HEAD_LINE_TRACKER);
    print_out("***         Running on %d MHz         ***", getCpuFrequencyMhz());
    print_out("***     Dual Core Setup: ISR Core 0    ***");
    print_out("***     Application Tasks on Core 1    ***");
    print_out_tbl(HEAD_LINE_VERSION);

    // Initialize EEPROM manager
    EepromManager::begin(512); // SIZE = 5 x presets = 5 x 32 bytes = 160 bytes
    uint8_t langNum = 0;
    EepromManager::readObject(LANG_EEPROM_ADDR, langNum);

    if (langNum >= LANG_COUNT)
        language = static_cast<Languages>(0);
    else
        language = static_cast<Languages>(langNum);

    // Initialize the pins
    pinMode(INTERV_PIN, OUTPUT);
    pinMode(STATUS_LED, OUTPUT);
    pinMode(AXIS1_STEP, OUTPUT);
    pinMode(AXIS1_DIR, OUTPUT);
    pinMode(EN12_n, OUTPUT);
    digitalWrite(AXIS1_STEP, LOW);
    digitalWrite(EN12_n, LOW);
    // handleExposureSettings();

    // Initialize Wifi and web server
    setupWireless();

    // Initialize the console serial
    setup_terminal(&term);

    if (xTaskCreatePinnedToCore(consoleTask, "console", 4096, NULL, 1, NULL, 1))
        print_out_tbl(TSK_START_CONSOLE);

    if (xTaskCreatePinnedToCore(intervalometerTask, "intervalometer", 4096, NULL, 1, NULL, 1))
        print_out_tbl(TSK_START_INTERVALOMETER);
    // Increase webserver task stack size to handle large HTML responses and concurrent connections
    if (xTaskCreatePinnedToCore(webserverTask, "webserver", 8192, NULL, 1, NULL, 1))
        print_out_tbl(TSK_START_WEBSERVER);

    // Give tasks time to fully initialize before starting axis
    vTaskDelay(100);
    print_out("Initializing axis with TMC driver...");

    ra_axis.begin();
}

void loop()
{
    int delay_ticks = 0;
    trackingRates.readTrackingRatePresetsFromEEPROM();

    if (DEFAULT_ENABLE_TRACKING == 1)
    {
        ra_axis.startTracking(ra_axis.rate.tracking, ra_axis.direction.tracking);
    }

    for (;;)
    {
        if (ra_axis.slewActive)
        {
            // Blink status LED if mount is in slew mode
            digitalWrite(STATUS_LED, !digitalRead(STATUS_LED));
            delay_ticks = 150; // Delay for 150 ms
        }
        else
        {
            // Turn on status LED if sidereal tracking is ON
            digitalWrite(STATUS_LED, ra_axis.trackingActive ? HIGH : LOW);
            delay_ticks = 1000; // Delay for 1 second
        }
        ra_axis.print_status();
        vTaskDelay(delay_ticks);
    }
}

void webserverTask(void* pvParameters)
{
    for (;;)
    {
        server.handleClient();
        vTaskDelay(1);
    }
}

void intervalometerTask(void* pvParameters)
{
    intervalometer = new Intervalometer(INTERV_PIN);
    intervalometer->readPresetsFromEEPROM();

    for (;;)
    {
        if (intervalometer->isActive())
            intervalometer->cleanup();
        vTaskDelay(1);
    }
}

void uartTask(void* pvParameters)
{
    for (;;)
    {
        uart_task();
        vTaskDelay(1);
    }
}

void consoleTask(void* pvParameters)
{
    for (;;)
    {
        term.readSerial();
        vTaskDelay(1);
    }
}

/**
 * @brief System shutdown and reset
 *
 * Stops motors, cleans up critical resources, and performs hard reset.
 * The reset() function jump provides more complete memory cleanup than ESP.restart()
 */
void (*resetFunc)(void) = 0; // declare reset function at address 0

void systemShutdown()
{
    print_out("[SHUTDOWN] System restart initiated...");

    // Stop motors for safety
    ra_axis.stopTracking();
    ra_axis.stopSlew();
    ra_axis.stopGotoTarget();
    intervalometer->abortCapture();
    intervalometer->cleanup();
    server.stop();
    server.close();
    WiFi.disconnect(true);
    WiFi.mode(WIFI_OFF);

    vTaskDelay(2000);
    print_out("[SHUTDOWN] Goodbye!");
    vTaskDelay(500);

    resetFunc();
}

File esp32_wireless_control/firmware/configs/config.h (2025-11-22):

#ifndef CONFIG
#define CONFIG 1

#ifdef HAVE_WIFI_CONFIG
#include "wifi_config.h"
#endif

#include "pins_config.h"

#define STEPPER_0_9 0 // 0.9 degree stepper motor
#define STEPPER_1_8 1 // 1.8 degree stepper motor

#define TRACKING_RATE_BOARD_V2 1

#define MOTOR_TRACKING_RATE TRACKING_RATE_BOARD_V2

/*To build in Arduino IDE, install esp32 boards V3.0x and the Arduinojson library by Benoit
 * Blanchon*/
/*****USER DEFINED*****/
// AP mode by default: ESP32 will create a wifi network which you can connect to
#define c_DIRECTION 1                // 1 is for north hemisphere and 0 for south hemisphere
#define RA_INVERT_DIR_PIN 1          // if need to invert direction pin set to 1
#define DEC_INVERT_DIR_PIN 0         // if need to invert direction pin set to 1
#define DEFAULT_ENABLE_TRACKING 1    // set to 1 to enable tracking at startup
#define DITHER_DISTANCE_X10_PIXELS 5 // set max distance to dither in multiple of 10 pixels
#define MAX_CUSTOM_SLEW_RATE 400     // Set max custom slew rate to X tracking rate
#define MIN_CUSTOM_SLEW_RATE 2       // Set min custom slew rate to X tracking rate

#ifndef TRACKING_RATE
// Available tracking rates:
// TRACKING_SIDEREAL
// TRACKING_SOLAR
// TRACKING_LUNAR
#define TRACKING_RATE TRACKING_SIDEREAL // default tracking rate
#endif

// Set the microstepping for the stepper motor
#ifndef TRACKER_MOTOR_MICROSTEPPING
#define TRACKER_MOTOR_MICROSTEPPING 64 // Default to 64 microstepping mode
#endif

// Configure the stepper motor type
#ifndef STEPPER_TYPE
#define STEPPER_TYPE STEPPER_0_9 // 0.9 degree stepper motor
#endif
// Configure the wifi settings if you are not using platformio
#ifndef WIFI_SSID
#define WIFI_SSID "OG Star Tracker" // change to your SSID
#endif
#ifndef WIFI_PASSWORD
#define WIFI_PASSWORD "password123" // change to your password, must be 8+ characters
#endif
// If you are using AP mode, you can access the website using the below URL
#ifndef MDNS_NAME
#define MDNS_NAME "tracker"
#endif
#ifndef WEBSERVER_PORT
#define WEBSERVER_PORT 80
#endif
// Enable debug printouts
#ifndef DEBUG
#define DEBUG 0
#endif

// try to update every time there is breaking change
#ifndef INTERNAL_VERSION
#define INTERNAL_VERSION 8
#endif
/**********************/

#define TMC_R_SENSE 0.11f // Match to your driver
#define AXIS_SERIAL_PORT Serial2
#define AXIS_RX 16
#define AXIS_TX 19

#define AXIS1_ADDR 0
#define AXIS2_ADDR 1

/**********************/
// Configure microstepping driver type
#define USE_MSx_PINS_MICROSTEPPING 1
#define USE_TMC_DRIVER_MICROSTEPPING 2

#ifndef MICROSTEPPING_MOTOR_DRIVER
#define MICROSTEPPING_MOTOR_DRIVER USE_TMC_DRIVER_MICROSTEPPING // Default to tmc driver
#endif

/*****DO NOT MODIFY BELOW*****/
// Set the resolution per step for the stepper motor
#if STEPPER_TYPE == STEPPER_0_9
#define ARCSEC_PER_STEP 2.0
#else
#define ARCSEC_PER_STEP 4.0
#endif

// LEDs for intervalometer status and general purpose status led
#define INTERV_PIN 25
#define STATUS_LED 26 // (Red)
#define LANG_EEPROM_ADDR 0
#define PRESETS_EEPROM_START_LOCATION 1
// Start after intervalometer presets (10 * 28 bytes)
#define TRACKING_RATE_PRESETS_EEPROM_START_LOCATION 300

// Stepper driver pins -- intended for TMC2209 for now
// AXIS 1 - RA
#define AXIS1_STEP 5
#define AXIS1_DIR 15
#define SPREAD_1 4
// AXIS 2 - DEC
#define AXIS2_STEP 19
#define AXIS2_DIR 18
#define SPREAD_2 21
// common pins
#define RA_MS1 23
#define RA_MS2 22
#define EN12_n 17

#endif

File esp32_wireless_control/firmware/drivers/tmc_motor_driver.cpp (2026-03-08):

#include "tmc_motor_driver.h"
#include "uart.h"

TmcMotorDriver::TmcMotorDriver(HardwareSerial* serialPort, uint8_t addr, float rSense,
                               uint8_t rxPin, uint8_t txPin)
    : serialPort(serialPort), addr(addr), tmc_driver(serialPort, rSense, addr)
{
    if (serialPort != nullptr)
    {
        serialPort->begin(115200, SERIAL_8N1, rxPin, txPin);
        while (!serialPort)
            ;
    }

    tmc_driver.begin();
    tmc_driver.pdn_disable(true);      // enable pdn_uart
    tmc_driver.mstep_reg_select(true); // Use MRES register for microstepping
    tmc_driver.VACTUAL(0);             // Enable stepping by step pin

    tmc_driver.I_scale_analog(false); // Use internal current scaling and ignore potentiometer

    // Basic initialization only - advanced settings moved to setMicrosteps()
    tmc_driver.rms_current(1000, 0.6); // Higher initial current: 1000mA run, 600mA hold
    tmc_driver.push();                 // Push basic settings to driver
}

void TmcMotorDriver::setMicrosteps(uint16_t microsteps)
{
    tmc_driver.microsteps(microsteps);

    // IRUN: 1400mA (87% of 1.6A max for NEMA17) for strong torque during movement
    // IHOLD: 1120mA (80% of IRUN) for reliable position holding under load
    tmc_driver.rms_current(1400, 0.8); // 1400mA run, 1120mA hold
    tmc_driver.iholddelay(12);         // Hold delay for load stability
    tmc_driver.TPOWERDOWN(25);         // Extended power down delay for heavy loads

    // Apply StealthChop settings
    tmc_driver.en_spreadCycle(false); // Use StealthChop for quiet operation
    tmc_driver.pwm_autoscale(true);   // Enable automatic PWM scaling

    // Push all settings at once
    tmc_driver.push();

    uint16_t actual_microsteps = tmc_driver.microsteps();
    uint16_t actual_rms_current = tmc_driver.rms_current();

#if DEBUG == 1
    print_out("Microsteps set:");
    print_out("  Requested: %d, Actual: %d", microsteps, actual_microsteps);
    print_out("  RMS Current: %d mA", actual_rms_current);
    print_out("  Hold Current: %d mA", (uint16_t) (actual_rms_current * 0.8));
#endif

    if (microsteps != actual_microsteps)
    {
        print_out("WARNING: Microstep setting mismatch!");
    }
}

void TmcMotorDriver::setDirection(bool direction)
{
    tmc_driver.shaft(direction);
    tmc_driver.push();
}

void TmcMotorDriver::print_status()
{
#if DEBUG == 1
    uint8_t ihold_raw = tmc_driver.ihold();
    uint16_t rms_current = tmc_driver.rms_current();

    // Hold current = RMS_current * (IHOLD/32) where IHOLD is 0-31
    uint16_t hold_current = (uint16_t) (rms_current * ihold_raw / 32.0);

    print_out("TMC Driver Status:");
    print_out("  RMS Current: %d mA", tmc_driver.rms_current());
    print_out("  Hold Current: %d mA (IHOLD=%d/32 of IRUN)", hold_current, ihold_raw);
    print_out("  Microsteps: %d", tmc_driver.microsteps());
    print_out("  irun: %d", tmc_driver.irun());
    print_out("  ihold: %d", tmc_driver.ihold());
    print_out("  iholddelay: %d", tmc_driver.iholddelay());
    print_out("  TPOWERDOWN: %d", tmc_driver.TPOWERDOWN());

    // StealthChop settings
    print_out("StealthChop Settings:");
    print_out("  SpreadCycle enabled: %s", tmc_driver.en_spreadCycle() ? "true" : "false");
    print_out("  PWM autoscale: %s", tmc_driver.pwm_autoscale() ? "true" : "false");
    print_out("  PWM autograd: %s", tmc_driver.pwm_autograd() ? "true" : "false");
    print_out("  TPWMTHRS: %d", tmc_driver.TPWMTHRS());

    // Read back GCONF register values
    print_out("GCONF Settings:");
    print_out("  pdn_disable: %s", tmc_driver.pdn_disable() ? "true" : "false");
    print_out("  mstep_reg_select: %s", tmc_driver.mstep_reg_select() ? "true" : "false");

    // Read driver status flags
    print_out("Driver Status:");
    print_out("  Driver enabled: %s", tmc_driver.isEnabled() ? "true" : "false");
    print_out("  Communication OK: %s", tmc_driver.test_connection() == 0 ? "true" : "false");

    // Read GSTAT error registers
    bool drv_error = tmc_driver.drv_err();
    bool uv_cp_error = tmc_driver.uv_cp();
    bool reset_flag = tmc_driver.reset();

    print_out("TMC Error Status (GSTAT):");
    print_out("  Driver Error (drv_err): %s", drv_error ? "ERROR" : "OK");
    print_out("  Undervoltage/Charge Pump (uv_cp): %s", uv_cp_error ? "ERROR" : "OK");
    print_out("  Reset Flag: %s", reset_flag ? "RESET OCCURRED" : "OK");

    // Clear GSTAT flags by writing back the read values
    // This clears the latched error flags
    if (drv_error || uv_cp_error || reset_flag)
    {
        print_out("*** TMC DRIVER HAS ERRORS - CLEARING GSTAT FLAGS ***");

        uint8_t gstat_clear = 0;
        if (reset_flag)
            gstat_clear |= 0x01; // Clear reset flag
        if (drv_error)
            gstat_clear |= 0x02; // Clear drv_err flag
        if (uv_cp_error)
            gstat_clear |= 0x04; // Clear uv_cp flag

        tmc_driver.GSTAT(gstat_clear);

        print_out("GSTAT error flags cleared (0x%02X)", gstat_clear);
        print_out("*** CHECK CONNECTIONS AND POWER - ERRORS WERE PRESENT ***");
    }
    else
    {
        print_out("TMC Driver: All GSTAT error flags clear");
    }
#endif
}

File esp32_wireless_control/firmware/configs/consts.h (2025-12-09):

#ifndef _CONSTS_H_
#define _CONSTS_H_

#include "config.h"

#define SIDEREAL_DAY_MS 86164000UL
#define SOLAR_DAY_MS 86400000UL
#define LUNAR_DAY_MS 88253300UL

#define RA_SECONDS_PER_FULL_REV 86400 // 24 hours * 3600 seconds/hour

#define MAX_MICROSTEPS 256UL

#define GEAR_RATIO 101.25

// Timer frequency used for hardware timer (40MHz APB clock)
#define TIMER_APB_CLK_FREQ 40000000UL

// Gear ratio as integers to avoid floating point in enum calculations
#define GEAR_RATIO_NUM 405 // 101.25 * 4 = 405
#define GEAR_RATIO_DEN 4   // Denominator = 4

#if STEPPER_TYPE == STEPPER_0_9
// Define steps per revolution based on stepper type
#define STEPPER_STEPS_PER_REV 400
#else
#define STEPPER_STEPS_PER_REV 200
#endif

#define STEPS_PER_TRACKER_FULL_REV (STEPPER_STEPS_PER_REV * GEAR_RATIO * MAX_MICROSTEPS)

// Steps per tracker full revolution using integer gear ratio (for enum calculations)
#define STEPS_PER_TRACKER_FULL_REV_INT                                                             \
    ((STEPPER_STEPS_PER_REV * GEAR_RATIO_NUM * MAX_MICROSTEPS) / GEAR_RATIO_DEN)

#endif /* _CONSTS_H_ */

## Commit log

2024-11-06 firmware: add platformio compilation support
    This adds support to build the firmware for the esp32 devkit with
    platformio.
    It may not be clean but until classes are introduced this is the
    way to go.
2024-11-17 firmware: fix compile warnings by adding missing switch cases
    This has no functional change instead fixes compile warnings for
    not provided switch cases in the timer interval isr routine.
    [firmware.ino]
2024-12-09 Fix missing formatting
    Reformat the code with two spaces indented
    [config.h, firmware.ino]
2024-12-09 Fixed the bug of handleStatusRequest, which requires you to use getString(STR_SLEWING, currentLanguage) to get the return value after supporting multiple languages
    Restore the code order of the original handleStatusRequest method
    [firmware.ino]
2024-12-09 Fixed the bug of handleStatusRequest, which requires you to use getString(STR_SLEWING, currentLanguage) to get the return value after supporting multiple languages
    [firmware.ino]
2025-01-30 firmware: uart: add abstraction layer for serial in dedicated task
2025-01-30 firmware: replace serial.print with print_out
    [firmware.ino]
2025-01-31 fixup! firmware: uart: add abstraction layer for serial in dedicated task
    [uart.cpp]
2025-01-31 firmware: replace delay() with vTaskDelay()
    [firmware.ino]
2025-02-01 firmware: pin webserver task to core 0
    Handle dns requests in time by parallelizing the webserver and
    dnsserver to different cores.
2025-06-25 firmware: axis: fix goto ra step calculation
    [axis.cpp, config.h]
2025-07-05 firmware: dns: replaced DNSServer with mDNS which publish tracker in local network.
    [firmware.ino]
2025-07-05 Fixed usage of AP mode for v2 board
    [firmware.ino]
2025-07-23 firmware: platformio: set stepper type to 1.8°
2025-08-02 fixup! Added star database
    [firmware.ino]
2025-08-18 firmware: interface: add current position card
2025-08-18 firmware: add support for displaying the current position and longitude
2025-08-20 firmware: index: add support to fine tune tracking rate during runtime
    This can be useful to compensate slight drifting during tracking.
    Currently it supports adjusting the fixed rates by 1/10/100 steps
    in positive as well as negative direction.
    [firmware.ino]
2025-08-20 firmware: webserver: manually load the webpage from storage
    Load the page manually due to String implementation from Arduino
    truncates null terminated characters and therefor loses valuable
    content from the data that could render the page unusable.
2025-09-04 firmware: trackingrate: print warning when rate is set incorrectly
2025-09-05 firmware: reduce memory footprint
2025-09-13 mechanics: update printing files to latest instructables version
    [1 part of gearboox.stl, 2 part of gearbox.stl, 3 part of gearbox.stl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]
2025-09-13 upgrades: add first community upgrade by The1naruto
    [OGstartracker ONN battery mount.stl]
2025-09-13 upgrades: add surveyor tripod adapter by unfi_zero
    [size-test.stl, stationary_part_with_surveyor_adapter2.stl]
2025-09-13 upgrades: add beefier gearbox and multicolor support by Long
    [belt-cover-modded-needs_supports.stl, belt-tightener-625-bearing-m5x16mm.stl, belt-tightener-f695-bearing-m5x16mm.stl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]
2025-10-03 upgrades: add illuminated polarscope by Long
    [knob.stl, led-top-cap.stl, potentiometer-hole-cover.stl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]
2025-10-11 feat: Redesign timelapse pan functionality with continuous panning and night mode
    Major overhaul of the timelapse panning feature to make it more intuitive and add support for nighttime panoramas.
    - Pan angle now represents TOTAL angle (not per-shot angle)
    - Users with existing pan configurations must update their settings
    - Old: panAngle = 1° per shot × 30 shots = 30° total
    - New: panAngle = 30° total ÷ 30 shots = 1° per shot
    - `panAngle` now represents the total angle for the entire timelapse
    - More intuitive - users specify the full field of view to cover
    - Firmware calculates per-shot angle automatically
    - Updated in: intervalometer.h, intervalometer.cpp
    - DAY_TIME_LAPSE_PAN now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
    [firmware.ino]
2025-11-06 firmware: axis: add panning function
    Add a function to initiate panning of the tracker by leveraging
    the slewing functionality.
    Additionally fix a bug in the ISR by exeeding the axis counter value.
    [axis.cpp]
2025-11-06 firmware: intervalometer: refactor and abstract functions into own classes
    Remove the obsolet night timelapse functionality as it is already contained
    in the day timelapse. Unify it into a single timelapse mode.
    Now this introduces a new mode where we pan the mount during timelapse
    shooting. Currently we only pan while the delay.
    This mode is useful for shooting panoramas or startrails.
2025-11-22 firmware: ota-handler: introduce ota update functionality
    Add the OTA update functionality to the homepage and add endpoints
    for it.
    Document the endpoints later on.
    Enhance OTA interface with GitHub integration and progress tracking
    - Add automatic GitHub release checking with version comparison
    - Implement direct firmware download with real-time progress bars
    - Add polling for live update progress during downloads
    - Improve UI alignment with flexbox layout and better button styling
    - Include automatic page refresh after successful OTA completion
    - Add comprehensive error handling for network and update failures
    - TODO: clean up ota.html
    [firmware.ino]
2025-11-22 refactor: convert OTAHandler to singleton pattern
    - Replace dependency injection with singleton getInstance() pattern
    - Add private constructor and static instance management
    - Implement init() method for delayed WebServer initialization
    - Add comprehensive safety checks for null server pointer
    This change eliminates tight coupling between ApiHandler and OTAHandler.
2025-11-22 refactor: simplify ApiHandler with delegation to OTAHandler singleton
    - Remove OTAHandler dependency injection from constructor
    - Replace all OTA method implementations with delegation calls
    - Clean up include dependencies and member variables
    - Reduce ApiHandler complexity by ~300 lines of code
    - Establish clear separation of concerns between routing and OTA logic
    All OTA methods now delegate to OTAHandler::getInstance().handleX()
    providing cleaner architecture and reduced coupling.
2025-11-22 firmware: implement a safer shutdown mechanism
    Safely shutdown any axis, intervalometer, wifi and webserver work
    prior invoking the reset function to provide a cleaner start.
    [commands.cpp, firmware.ino]
2025-11-22 firmware: fix missing ota include
    [firmware.ino]
2025-11-22 firmware: configs: make motor driver selectable in platformio
2025-12-07 firmware: axis: fix wrong direction of goto
    This is an attempt to fix the goto functionality to move into the
    right direction. It uncovered alot of work below to clarify used
    variables in the context.
    What was actually necessary to make goto pan into the right direction
    is overwriting the absolute direction, setting the drivers
    direction directly.
    Furthermore goto didn't stop when the target was reached as the counting
    did not behave as expected with a bunch of microstepping conversion.
    [axis.cpp, commands.cpp, consts.h]
2026-03-08 firmware: drivers: use internal current scaling and ignore vref
